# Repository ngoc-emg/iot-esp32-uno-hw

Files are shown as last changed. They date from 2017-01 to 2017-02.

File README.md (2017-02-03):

# iot-esp32-uno-hw

## Features

- Power input 4V to 30V and 5V USB.
- Auto enter program mode via Serial - Pre-program OTA firmware.
- ESP32 and Arduino Library.
- Vietnamese doc support from [https://esp8266.vn](https://esp8266.vn).
- Open hardware with CC-BY-SA license.
- Design with KiCad.

## Hardware.

- Microcontroller: ESP-32 WROVER.
	- CPU: ESP-32.
	- Architecture: 32-bit with TSMC ultra-low power 40nm technology.
- Operating Voltage: 3.3V.
- IO Voltage: 3.3V.
- IO pin: 23 pin with 6 pin Analog (A0-A5).
- Support display with header oled.
- 1 reset button, 1 flash button.

### Schematic.

<<<<<<< HEAD
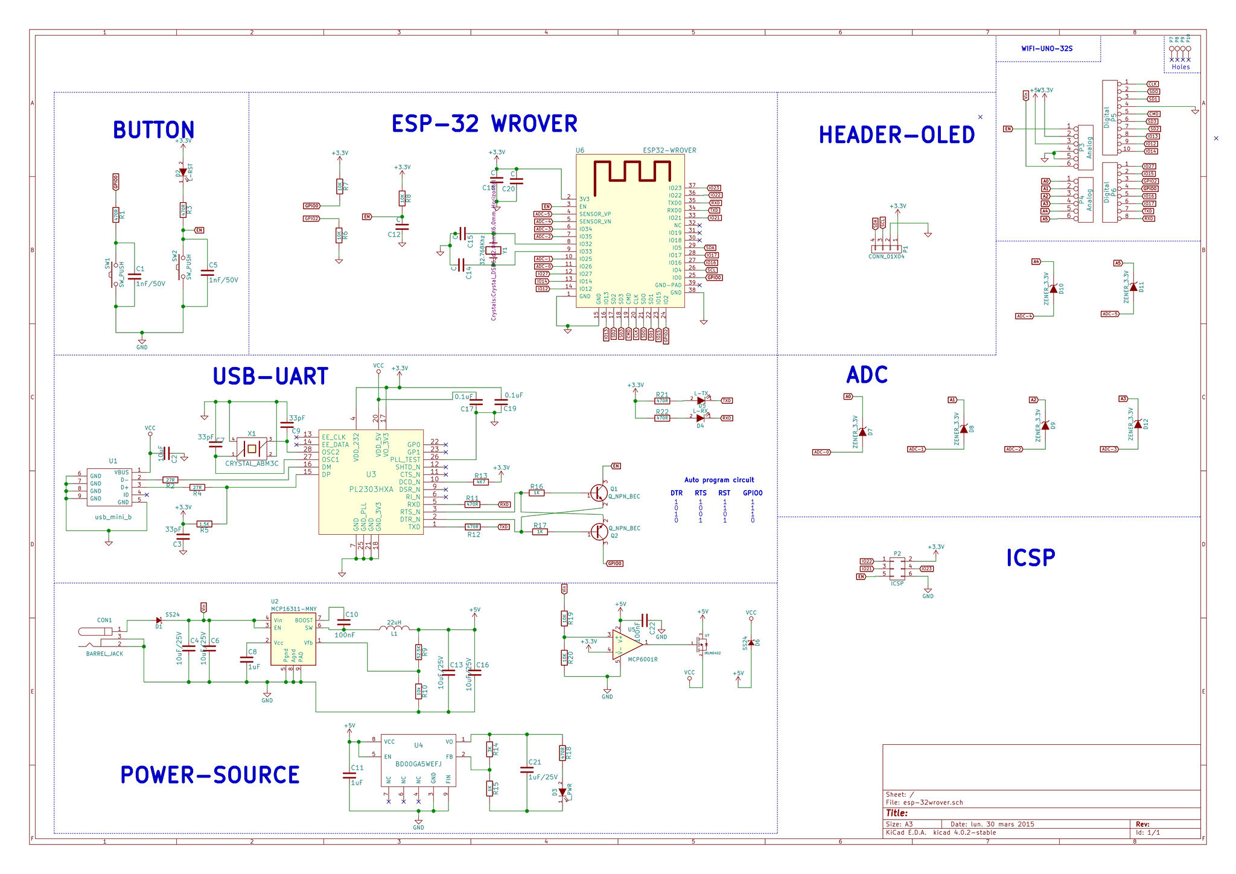
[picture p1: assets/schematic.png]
Sơ đồ nguyên l


### 3D

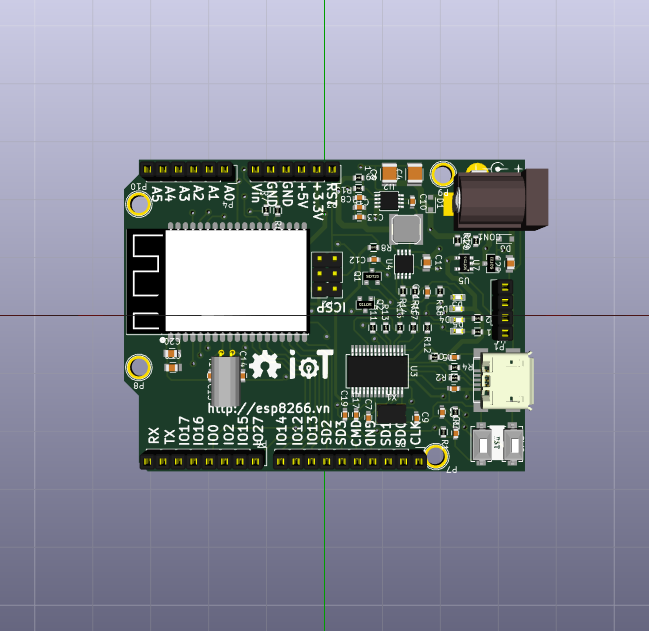
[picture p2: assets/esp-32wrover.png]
3D

=======

### 3D
>>>>>>> esp/master

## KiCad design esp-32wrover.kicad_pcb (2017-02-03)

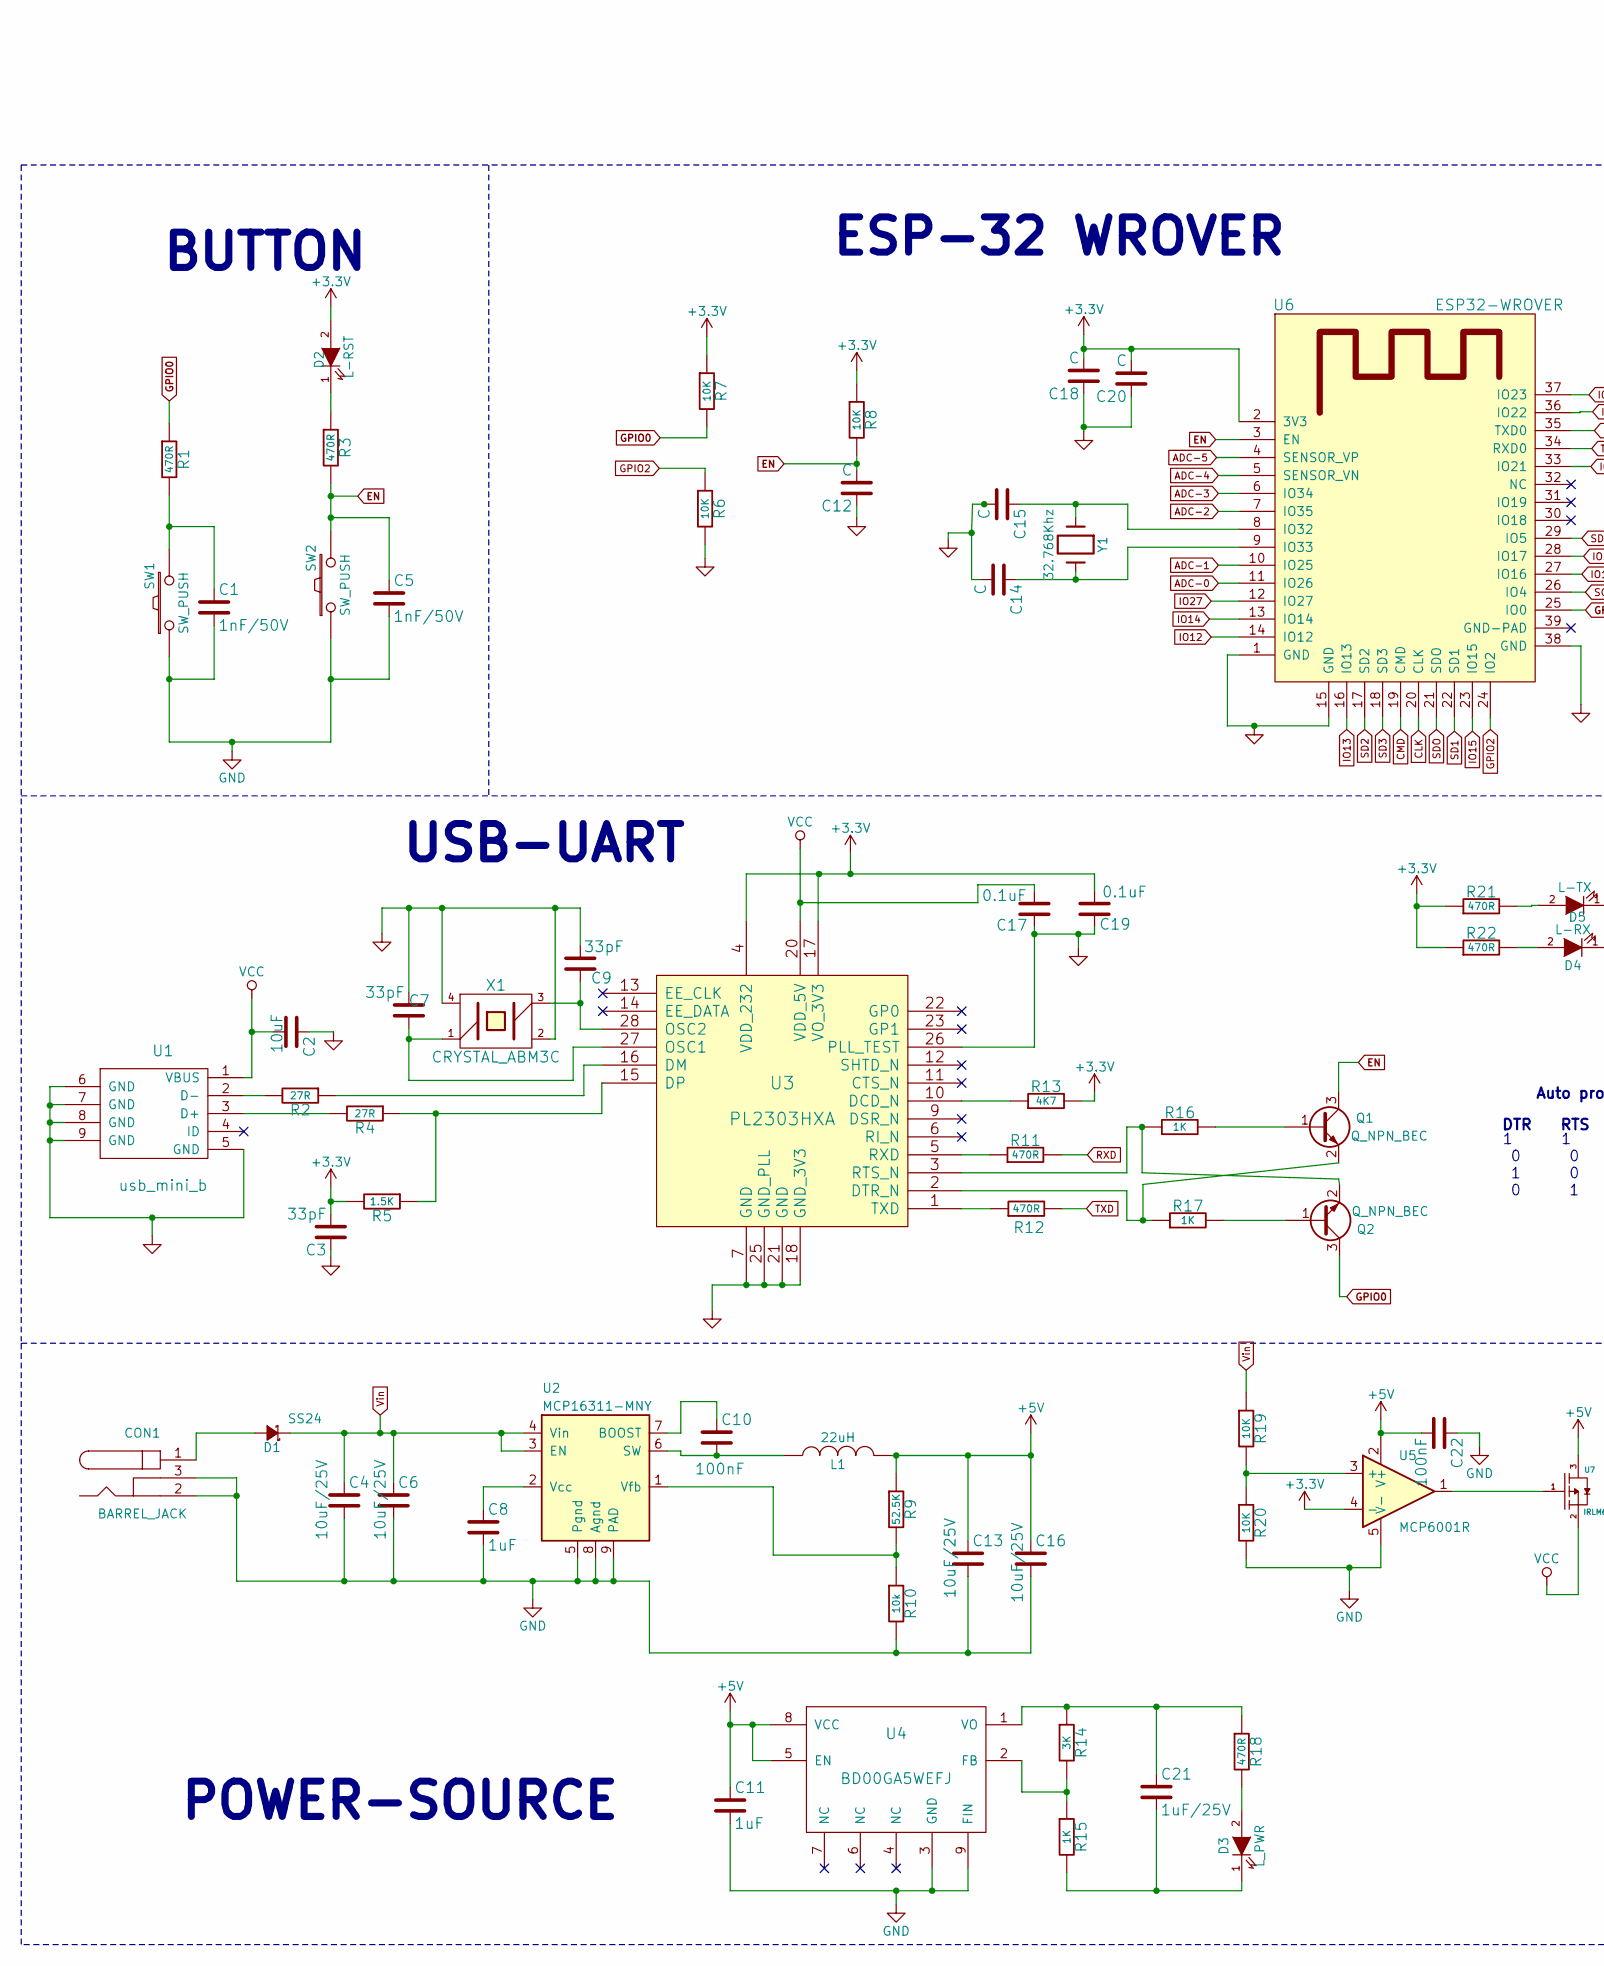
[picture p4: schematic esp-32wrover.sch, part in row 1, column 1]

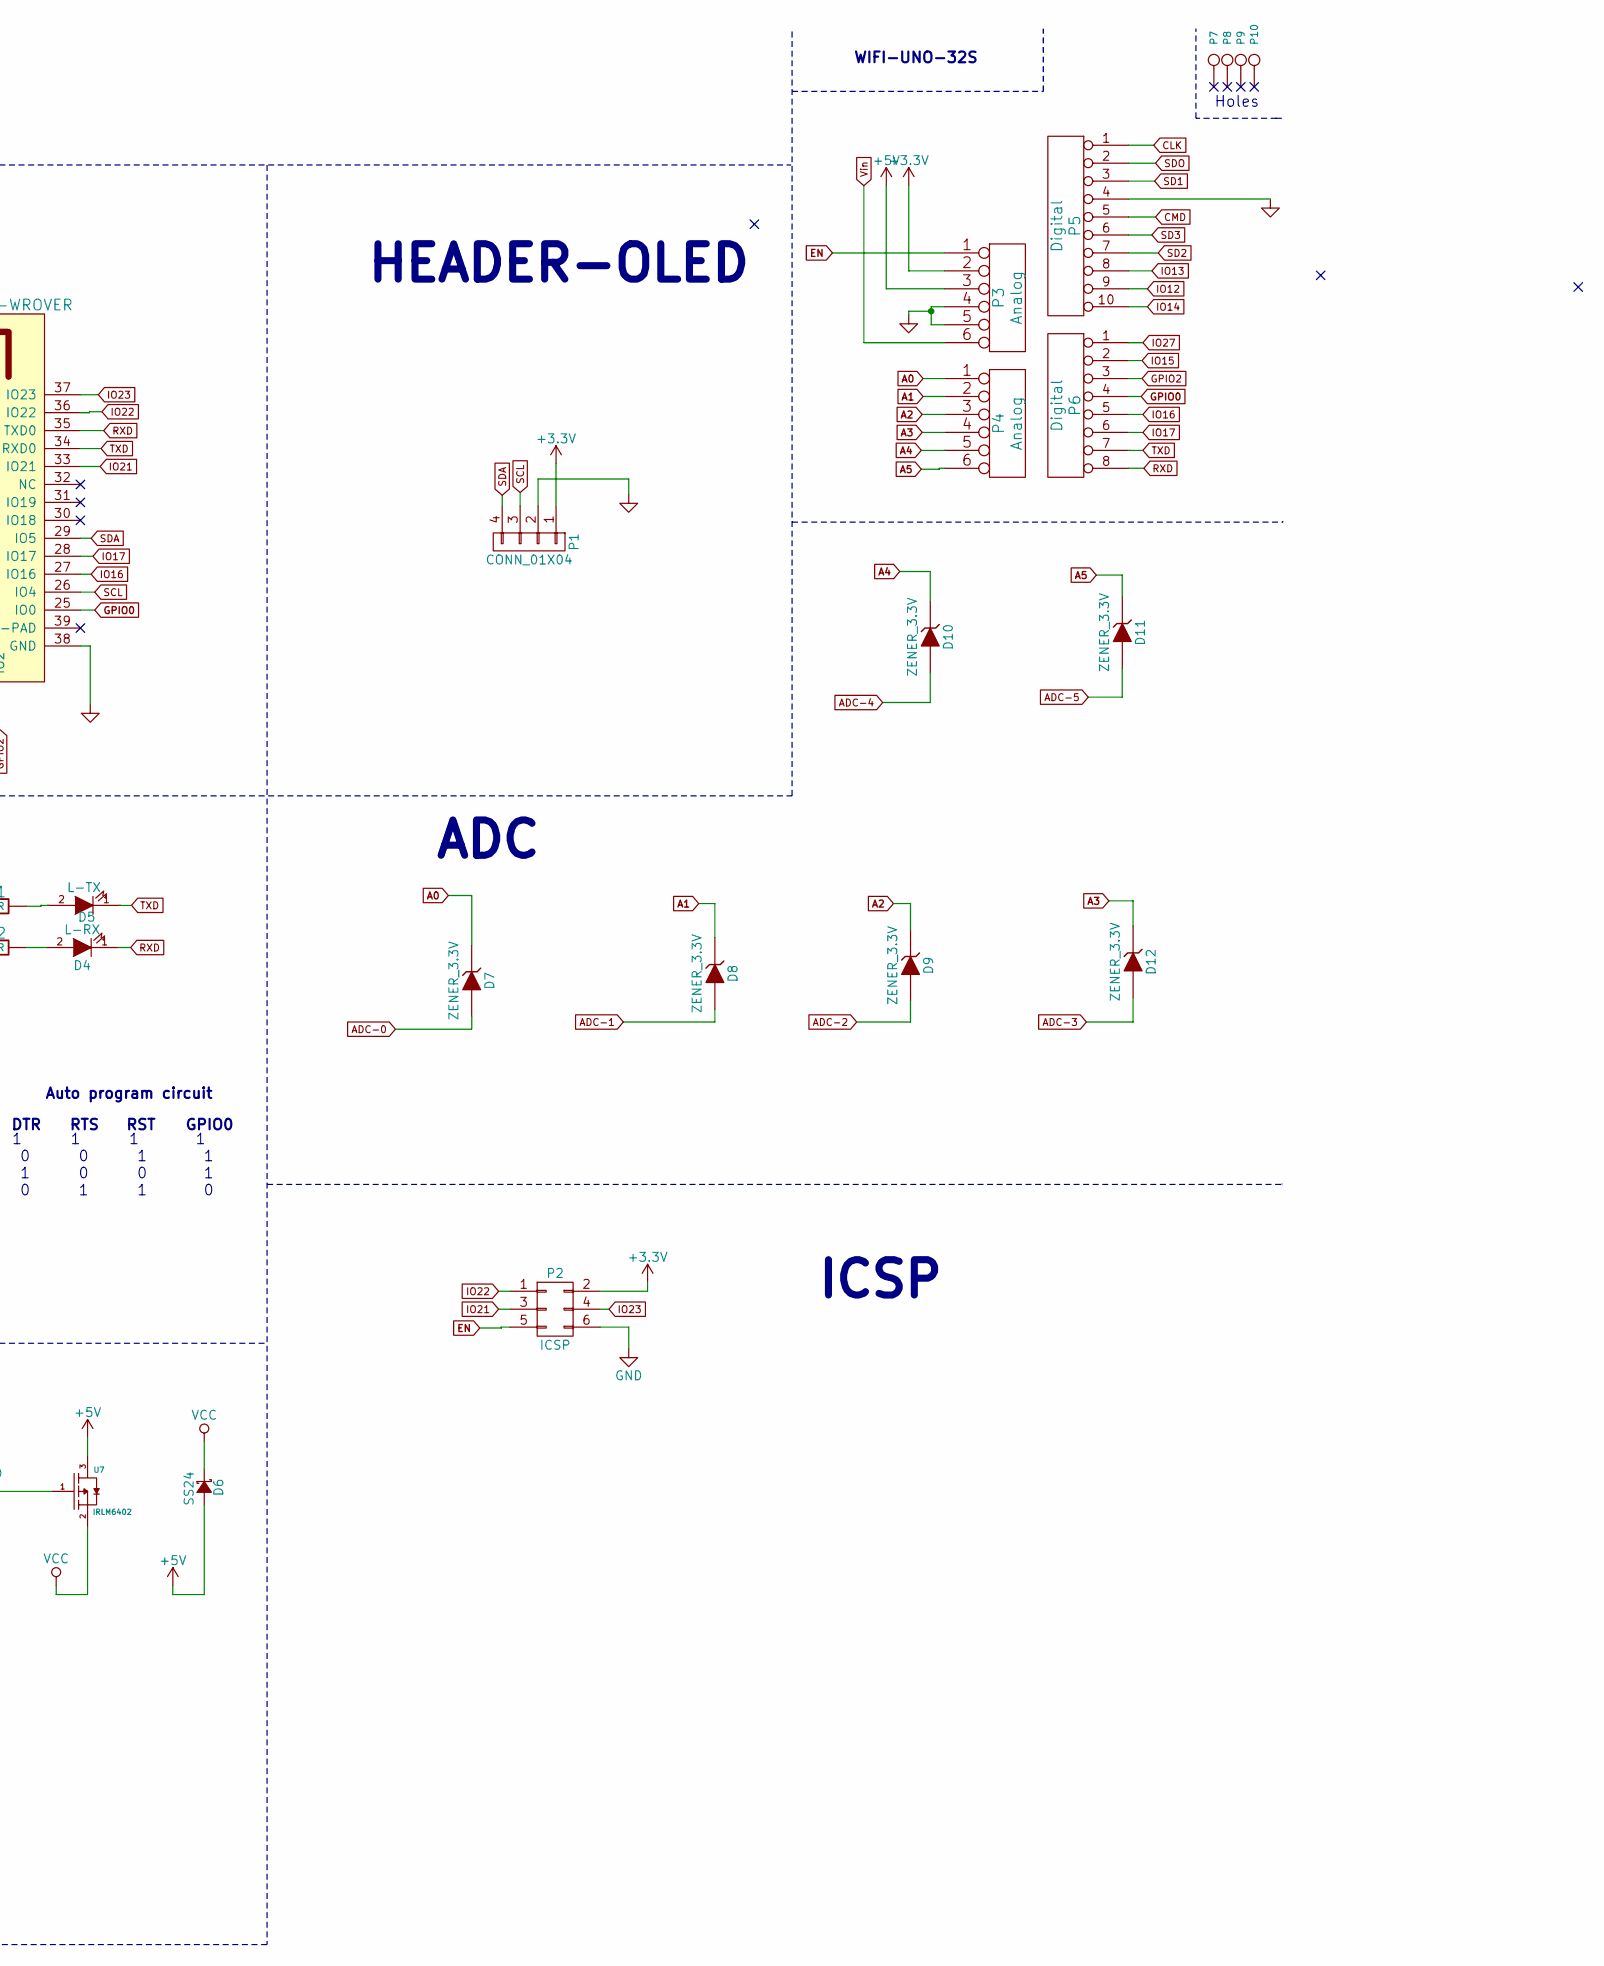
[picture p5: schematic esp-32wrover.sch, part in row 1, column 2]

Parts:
C1, C5: 1nF/50V; C_0603
C2: 10uF; C_0603
C3, C7, C9: 33pF; C_0603
C4, C6: 10uF/25V; C_1210
C8: 1uF; C_0603
C10: 100nF; C_0603
C11: 1uF; C_0805
C12, C14, C15: C; C_0603
C13, C16: 10uF/25V; C_0603
C17, C19: 0.1uF; C_0603
C18, C20: C; C_0805
C21: 1uF/25V; C_0603
C22: 100nF; C_0805
CON1: BARREL_JACK; JACK_ALIM
D1, D6: SS24; D_0805
D2: L-RST; LED_0603
D3: L_PWR; LED_0603
D4: L-RX; LED_0603
D5: L-TX; LED_0603
D7, D8, D9, D10, D11, D12: ZENER_3.3V; D_0603
L1: 22uH; SELF-WE-TPC_M
P1: CONN_01X04; Pin_Header_Straight_1x04_Pitch2.54mm
P2: ICSP; Pin_Header_Straight_2x03_Pitch2.54mm
P3, P4: Analog; Socket_Strip_Arduino_1x06
P5: Digital; Socket_Strip_Arduino_1x10
P6: Digital; Socket_Strip_Arduino_1x08
P7, P8, P9, P10: CONN_1; Arduino_1pin
Q1, Q2: Q_NPN_BEC; SOT-23
R1, R3, R11, R12, R18, R21, R22: 470R; R_0603
R2, R4: 27R; R_0603
R5: 1.5K; R_0603
R6, R7, R8, R19, R20: 10K; R_0603
R9: 52.5K; R_0603
R10: 10k; R_0603
R13: 4K7; R_0603
R14: 3K; R_0603
R15, R16, R17: 1K; R_0603
SW1, SW2: SW_PUSH; SW_SPST_EVQPE1
U1: usb_mini_b; USB_Mini-B
U2: MCP16311-MNY; MSOP-8-1EP_3x3mm_Pitch0.65mm
U3: PL2303HXA; SSOP-28_5.3x10.2mm_Pitch0.65mm
U4: BD00GA5WEFJ; MSOP-8-1EP_3x3mm_Pitch0.65mm
U5: MCP6001R; SOT-23-5
U6: ESP32-WROVER; esp32-wrover
U7: IRLM6402; SOT-23
X1: CRYSTAL_ABM3C; Crystal_SMD_5032-4pin_5.0x3.2mm
Y1: 32.768Khz; Crystal_DS26_d2.0mm_l6.0mm_Horizontal

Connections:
+3V3: C3.2, C18.2, C19.2, C20.2, D2.2 (A), P1.1, P2.2, P3.2, R5.2, R7.1, R8.1, R13.2, R21.1, R22.1, U3.4 (VDD_232), U3.17 (VO_3V3), U5.4 (-), U6.2 (3V3)
+5V: C11.1, C13.1, C16.1, C22.2, D6.2 (A), L1.2, P3.3, R9.1, U4.5 (EN), U4.8 (VCC), U5.2 (V+), U7.3
A0: D7.1 (K), P4.1
A1: D8.1 (K), P4.2
A2: D9.1 (K), P4.3
A3: D12.1 (K), P4.4
A4: D10.1 (K), P4.5
A5: D11.1 (K), P4.6
ADC-0: D7.2 (A), U6.11 (IO26)
ADC-1: D8.2 (A), U6.10 (IO25)
ADC-2: D9.2 (A), U6.7 (IO35)
ADC-3: D12.2 (A), U6.6 (IO34)
ADC-4: D10.2 (A), U6.5 (SENSOR_VN)
ADC-5: D11.2 (A), U6.4 (SENSOR_VP)
CLK: P5.1, U6.20 (CLK)
CMD: P5.5, U6.19 (CMD)
EN: C5.1, C12.2, P2.5, P3.1, Q1.3 (C), R3.2, R8.2, SW2.2, U6.3 (EN)
GND: C1.2, C2.1, C3.1, C4.2, C5.2, C6.2, C7.2, C8.2, C9.2, C11.2, C12.1, C13.2, C14.2, C15.2, C16.2, C17.1, C18.1, C19.1, C20.1, C22.1, CON1.2, CON1.3, P1.2, P2.6, P3.4, P3.5, P5.4, R6.2, R10.2, R20.2, SW1.1, SW2.1, U1.5 (GND), U1.6 (GND), U1.7 (GND), U1.8 (GND), U1.9 (GND), U2.5 (Pgnd), U2.8 (Agnd), U2.9 (PAD), U3.7 (GND), U3.18 (GND_3V3), U3.21 (GND), U3.25 (GND_PLL), U3.26 (PLL_TEST), U4.3 (GND), U4.9 (FIN), U5.5 (V-), U6.1 (GND), U6.15 (GND), U6.38 (GND), X1.2 (GND), X1.4 (GND)
GPIO0: P6.4, Q2.3 (C), R1.1, R7.2, U6.25 (IO0)
GPIO2: P6.3, R6.1, U6.24 (IO2)
IO12: P5.9, U6.14 (IO12)
IO13: P5.8, U6.16 (IO13)
IO14: P5.10, U6.13 (IO14)
IO15: P6.2, U6.23 (IO15)
IO16: P6.5, U6.27 (IO16)
IO17: P6.6, U6.28 (IO17)
IO21: P2.3, U6.33 (IO21)
IO22: P2.1, U6.36 (IO22)
IO23: P2.4, U6.37 (IO23)
IO27: P6.1, U6.12 (IO27)
unnamed: C1.1, R1.2, SW1.2
unnamed: C7.1, U3.27 (OSC1), X1.1
unnamed: C8.1, U2.2 (Vcc)
unnamed: C9.1, U3.28 (OSC2), X1.3
unnamed: C10.1, U2.7 (BOOST)
unnamed: C10.2, L1.1, U2.6 (SW)
unnamed: C14.1, U6.9 (IO33), Y1.2
unnamed: C15.1, U6.8 (IO32), Y1.1
unnamed: C21.1, R14.1, R18.1, U4.1 (VO)
unnamed: C21.2, D3.1 (K), R15.2
unnamed: CON1.1, D1.2 (A)
unnamed: D2.1 (K), R3.1
unnamed: D3.2 (A), R18.2
unnamed: D4.2 (A), R22.2
unnamed: D5.2 (A), R21.2
unnamed: Q1.1 (B), R16.2
unnamed: Q1.2 (E), R17.1, U3.2 (DTR_N)
unnamed: Q2.1 (B), R17.2
unnamed: Q2.2 (E), R16.1, U3.3 (RTS_N)
unnamed: R2.1, U3.16 (DM)
unnamed: R2.2, U1.2 (D-)
unnamed: R4.1, R5.1, U3.15 (DP)
unnamed: R4.2, U1.3 (D+)
unnamed: R9.2, R10.1, U2.1 (Vfb)
unnamed: R11.1, U3.5 (RXD)
unnamed: R12.1, U3.1 (TXD)
unnamed: R13.1, U3.10 (DCD_N)
unnamed: R14.2, R15.1, U4.2 (FB)
unnamed: R19.2, R20.1, U5.3 (+)
unnamed: U5.1, U7.1
RXD: D4.1 (K), P6.8, R11.2, U6.35 (TXD0)
SCL: P1.3, U6.26 (IO4)
SD1: P5.3, U6.22 (SD1)
SD2: P5.7, U6.17 (SD2)
SD3: P5.6, U6.18 (SD3)
SDA: P1.4, U6.29 (IO5)
SDO: P5.2, U6.21 (SDO)
TXD: D5.1 (K), P6.7, R12.2, U6.34 (RXD0)
VCC: C2.2, C17.2, D6.1 (K), U1.1 (VBUS), U3.20 (VDD_5V), U7.2
Vin: C4.1, C6.1, D1.1 (K), P3.6, R19.1, U2.3 (EN), U2.4 (Vin)

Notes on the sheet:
Holes
WIFI-UNO-32S
POWER-SOURCE
USB-UART
BUTTON
HEADER-OLED
1 1 1 1 0 0 1 1 1 0 0 1 0 1 1 0
Auto program circuit
DTR
RTS
RST
GPIO0
ADC
ESP-32 WROVER
ICSP

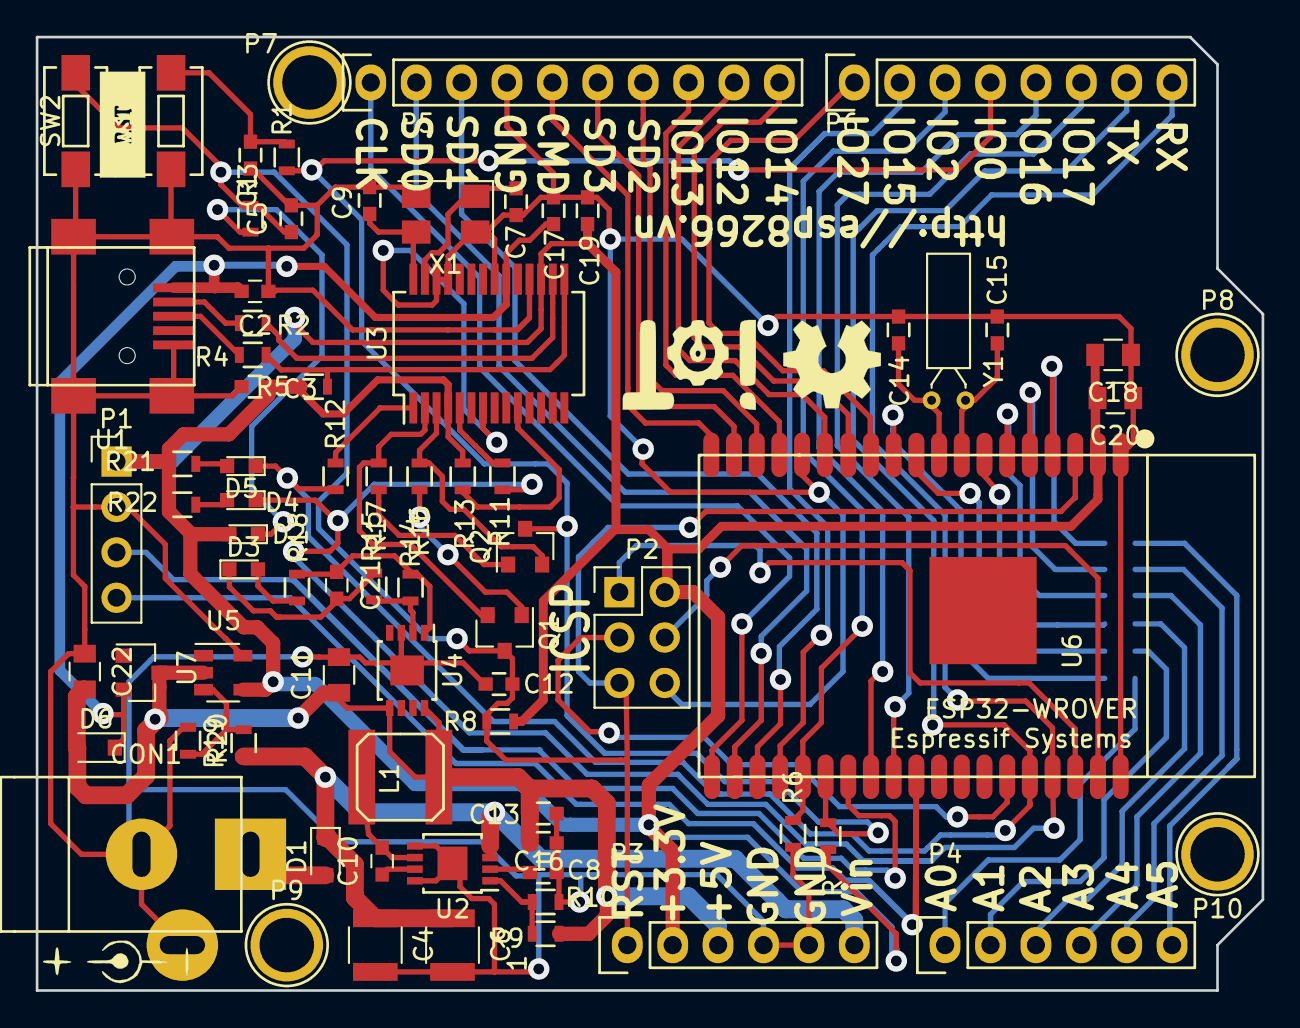
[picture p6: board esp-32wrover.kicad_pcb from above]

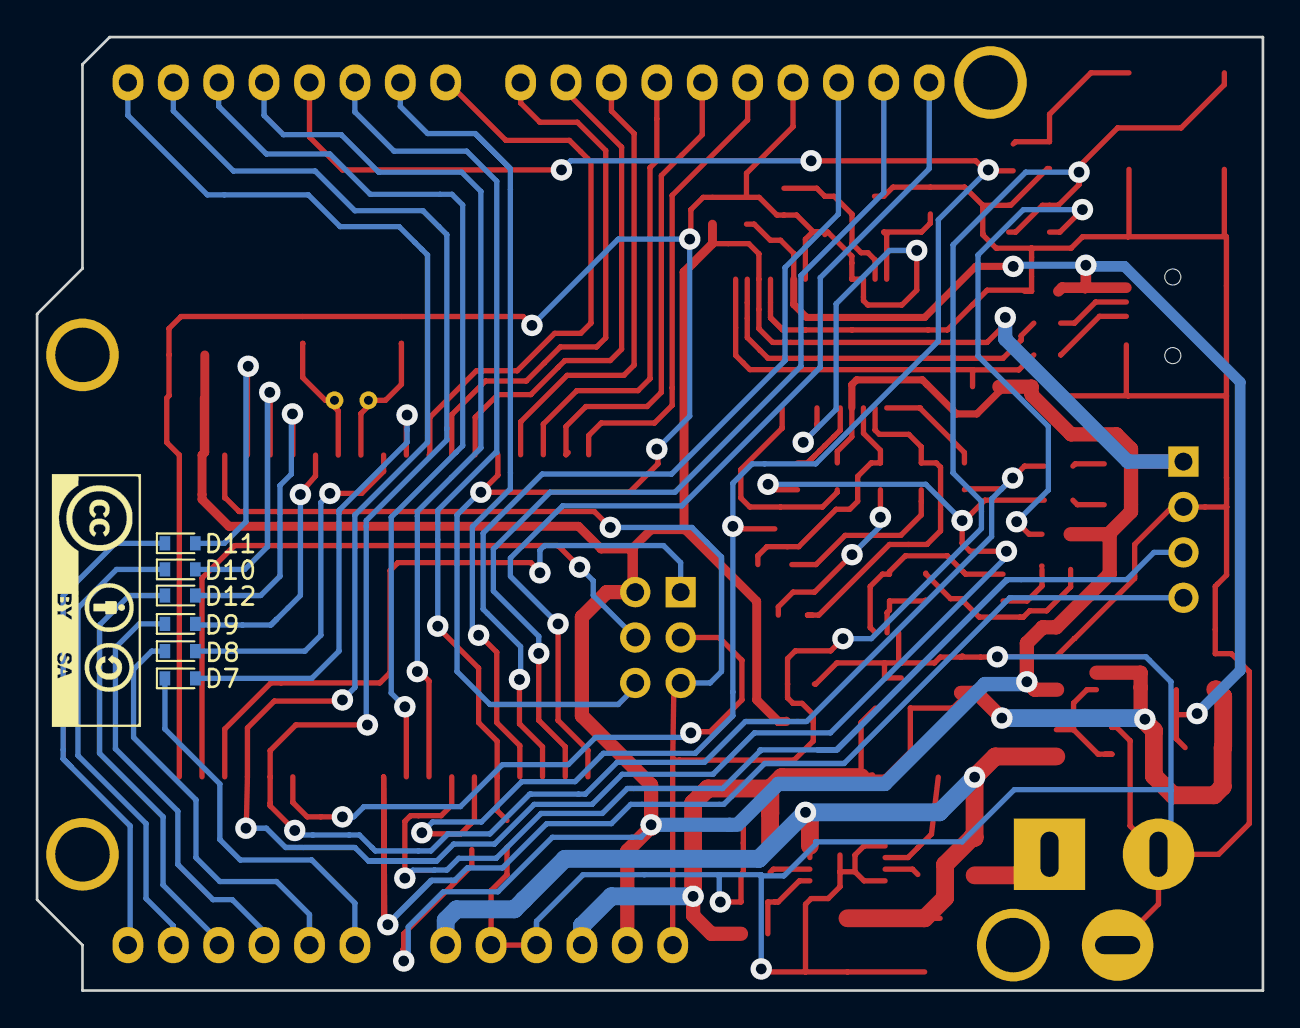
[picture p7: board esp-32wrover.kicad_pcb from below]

Board: 2 copper layers, 68.6 x 53.3 mm, 81 parts (6 on the bottom side), 70 nets.

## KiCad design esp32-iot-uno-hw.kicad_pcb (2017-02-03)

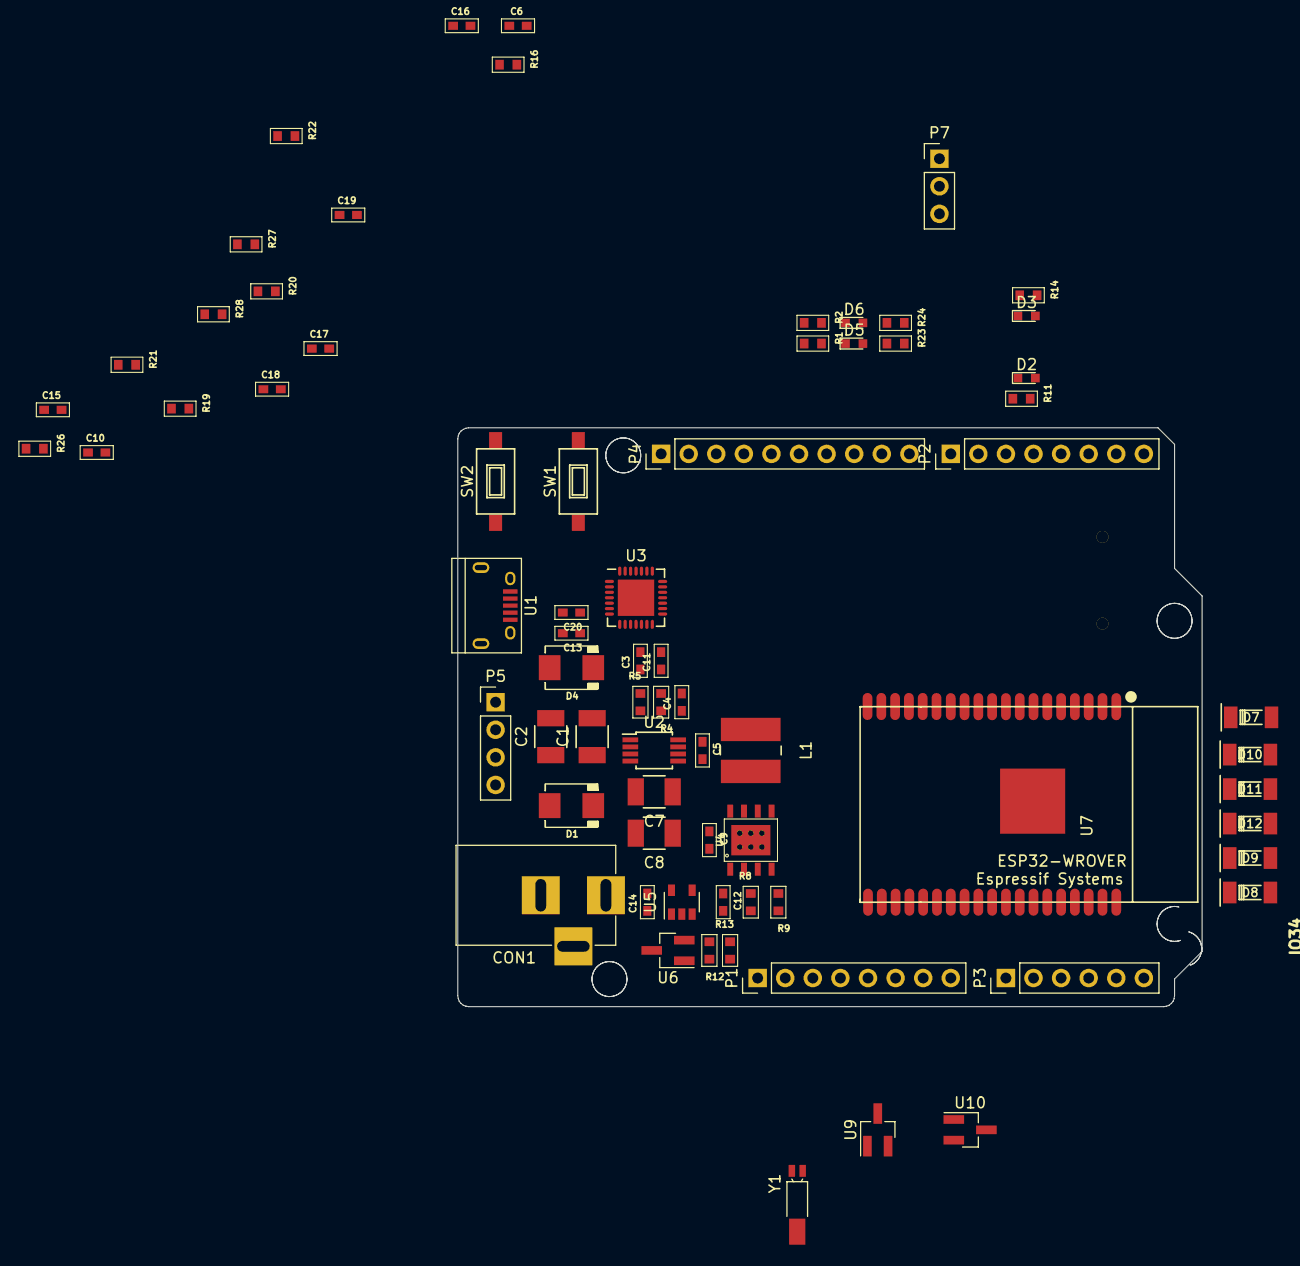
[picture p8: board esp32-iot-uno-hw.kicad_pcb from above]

Board: 2 copper layers, 68.5 x 53.3 mm, 73 parts (1 on the bottom side), 62 nets, no tracks yet.

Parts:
C1, C2: 10uF/50V; C_1210
C3, C18, C20: 10uF; C_0603
C4, C11, C13: 1uF; C_0603
C5, C14: 100nF; C_0603
C6, C10: 27pF/50V; C_0603
C7, C8: 10uF/25V; C_1210
C9, C12: 1uF/25V; C_0603
C15, C16: 0.1uF/50V; C_0603
C17: 0.1uF; C_0603
C19: 10uF/25V; C_0603
CON1: BARREL_JACK
D1, D4: SS24; do214aa-g
D2: Led_PWR_G; LED_0603
D3: LED_IO7_W; LED_0603
D5: TXD_Y; LED_0603
D6: RXD_B; LED_0603
D7, D8, D9, D10, D11, D12: D_Zener_3.3V; SOD-80
L1: 22uH; Choke_SMD_Wuerth-WE-PD2-Typ-MS
P1, P2: GPIO; Pin_Header_Straight_1x08_Pitch2.54mm
P3: ADC; Pin_Header_Straight_1x06_Pitch2.54mm
P4: GPIO; Pin_Header_Straight_1x10_Pitch2.54mm
P5: OLED; Pin_Header_Straight_1x04_Pitch2.54mm
P7: SD CARD; Pin_Header_Straight_1x03_Pitch2.54mm
R1, R2, R11, R14, R16, R19: 470R; R_0603
R4: 52.5K; R_0603
R5, R12, R13, R20: 10k; R_0603
R8: 3K/1%; R_0603
R9: 1K/1%; R_0603
R21, R26, R27, R28: 10k/1%; R_0603
R22: 5k/1% (NC ); R_0603
R23, R24: 1K; R_0603
S1: SD_CARD; MicroSD_Push-Push-A
SW1: EN; Tact_Switch_TS6X3.6
SW2: IO8; Tact_Switch_TS6X3.6
U1: usb_mini_b; USB_Micro-B
U2: MCP16311-MNY; MSOP-8_3x3mm_Pitch0.65mm
U3: CP2102; QFN-28-1EP_5x5mm_Pitch0.5mm
U4: BD00GA5WEFJ; HTSOP-J8
U5: MCP6001R; SOT-23-5
U6: IRLM6402; SOT-23_Handsoldering
U7: ESP32-WROVER-V3; esp32-wrover
U9, U10: MOSFET-N; SOT-23_Handsoldering
Y1: KDS-32.768KHz-2x6; Crystal_SMD_MicroCrystal_MS3V-T1R

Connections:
+3V3: C12.1, C13.1, C17.1, C18.1, C19.1, C20.1, P1.4, P1.5, P5.1, R8.1, R11.1, R14.1, R20.2, R21.2, R23.2, R24.2, R26.2, R27.2, R28.2, S1.4, U3.6, U3.7, U4.1, U5.4, U7.2
+5V: C7.1, C8.1, C9.1, C14.1, D4.1, L1.2, R4.1, U4.5, U4.8, U5.2, U6.2
A0/IO36: D8.1, P3.1
A1/IO39: D9.1, P3.2
A2/IO14: D10.1, P3.3
A3/IO12: D11.1, P3.4
A4/IO13: D12.1, P3.5
A5/IO15: D7.1, P3.6
ADC1_0/IO36: D8.2, U7.4
ADC1_3/IO39: D9.2, U7.5
CLK/GPIO6: P1.2, U7.20
CMD/IO11: P1.1, U7.19
D+: U1.3, U3.4
D-: U1.2, U3.5
DTR: U3.28, U9.1, U10.2
EN: C15.1, P1.3, R16.1, R20.1, U7.3, U9.3
GND: C1.2, C2.2, C3.2, C4.2, C6.2, C7.2, C8.2, C9.2, C10.2, C11.2, C12.2, C13.2, C14.2, C15.2, C16.2, C17.2, C18.2, C20.2, CON1.2, CON1.3, D2.1, P1.6, P1.7, P5.2, R5.2, R9.2, R13.1, R22.1, SW1.1, SW2.1, U1.5, U1.6, U2.5, U2.8, U3.3, U4.3, U4.9, U5.5, U7.1, U7.15, U7.38
IO0: P2.5, R21.1, U7.25, U10.3
IO2/DATA0: P2.6, P7.1, R26.1, S1.7, U7.24
IO5: P4.3, U7.29
IO12: D11.2, U7.14
IO13: D12.2, U7.16
IO14/CLK: D10.2, P7.2, R27.1, S1.5, U7.13
IO15/CMD: D7.2, P7.3, R28.1, S1.3, U7.23
IO18: P4.6, U7.30
IO19: P4.5, U7.31
IO21/SDA: P5.4, U7.33
IO22/SCL: P5.3, U7.36
IO23: P4.4, U7.37
IO25: P2.3, U7.10
IO26: P2.2, U7.11
IO27: P2.1, U7.12
IO32: C6.1, U7.8, Y1.1
IO33: C10.1, U7.9, Y1.2
IO34: P4.9, U7.6
IO35: P4.10, U7.7
unnamed: C4.1, U2.2
unnamed: C5.1, U2.7
unnamed: C5.2, L1.1, U2.6
unnamed: C16.1, R19.2, SW2.2
unnamed: C19.2, S1.6
unnamed: CON1.1, D1.2
unnamed: D2.2, R11.2
unnamed: D3.2, R14.2
unnamed: D5.2, R23.1
unnamed: D6.2, R24.1
unnamed: R4.2, R5.1, U2.1
unnamed: R8.2, R9.1, U4.2
unnamed: R12.1, R13.2, U5.3
unnamed: R16.2, SW1.2
unnamed: U5.1, U6.1
RTS: U3.24, U9.2, U10.1
RXD: R1.1, U7.34
RXD_CP2102: D6.1, R2.2, U3.25
SD0/IO07: D3.1, P4.8, U7.21
SD1/IO08: P4.7, R19.1, U7.22
TXD: R2.1, U7.35
TXD_CP2102: D5.1, R1.2, U3.26
U1RXD/GPIO9: P2.8, U7.17
U1TXD/GPIO10: P2.7, U7.18
VCC: C3.1, C11.1, D4.2, U1.1, U3.8, U6.3
Vin: C1.1, C2.1, D1.1, P1.8, R12.2, U2.3, U2.4

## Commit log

2017-01-05 bắt đầu vẽ mạch nguyên lý
    [esp-32wrover.kicad_pcb, esp-32wrover.sch]
2017-01-05 xoa file
    [esp-32wrover.kicad_pcb, esp-32wrover.sch]
2017-01-05 tạo khối usb
    [esp-32wrover.kicad_pcb, esp-32wrover.sch]
2017-01-06 tạo khối ADC
    [esp-32wrover.sch]
2017-01-06 nối IO
    [esp-32wrover.sch]
2017-01-06 noi io
    [esp-32wrover.sch]
2017-01-06 them noconnect
    [esp-32wrover.sch]
2017-01-07 add netlist
    [esp-32wrover.sch]
2017-01-07 edit netlist, create pcb
    [esp-32wrover.kicad_pcb, esp-32wrover.sch]
2017-01-09 thêm header ICSP
    [esp-32wrover.kicad_pcb, esp-32wrover.sch]
2017-01-09 edit .gitignore
    [esp-32wrover.kicad_pcb]
2017-01-10 sap xep linh kien
    [esp-32wrover.kicad_pcb, esp-32wrover.sch]
2017-01-11 đi dây PCB
    [esp-32wrover.kicad_pcb, esp-32wrover.sch]
2017-01-11 sủa lỗi kích thước via
2017-01-11 xoá file autosave
    [esp-32wrover.kicad_pcb]
2017-01-11 điều chỉnh độ rộng đường đi dây theo đúng quy cách
    [esp-32wrover.kicad_pcb]
2017-01-11 sửa thư viện chân cho esp32-wrover
    [esp-32wrover.kicad_pcb]
2017-01-16 sắp xếp linh kiện, đi dây
    [esp-32wrover.kicad_pcb, esp-32wrover.sch]
2017-01-16 thêm thư viện 3d cho esp32
    [esp-32wrover.kicad_pcb]
2017-01-17 edit esp-3d
    [esp-32wrover.kicad_pcb]
2017-01-18 edit readme
    [esp-32wrover.sch]
2017-01-19 cap nhat 3d cho pcb
    [esp-32wrover.kicad_pcb]
